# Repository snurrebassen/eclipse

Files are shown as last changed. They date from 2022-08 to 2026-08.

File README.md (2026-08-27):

# Eclipse

A 70% gasket-mount custom keyboard designed by [snurrebassen](https://geekhack.org/index.php?topic=113079), featuring a F-row-less TKL layout.

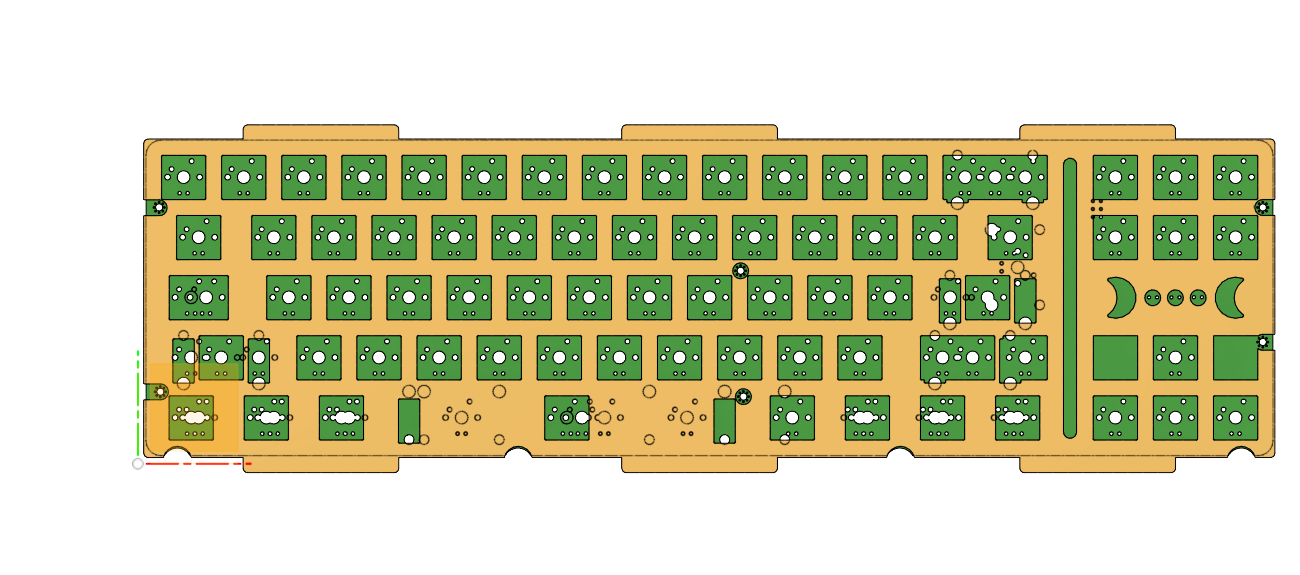
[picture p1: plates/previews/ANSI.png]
Eclipse


## Specifications

| Spec | Value |
|---|---|
| Layout | 70% (F-row-less TKL), 71 keys |
| Typing Angle | 7° |
| Front Height | 17.6mm |
| Dimensions | 374mm × 128.62mm |
| Mounting | Gasket mount (12× 50×5mm silicone gaskets) |
| Case Screws | 8× M3×11mm (bottom to top) |
| Daughterboard | 4× M2×4mm |
| Weight Screws | 2× M4×3.5mm (countersunk 90°) |

## Layout Compatibility

The Eclipse supports the following layouts:
- **ANSI**
- **ISO**
- Split-backspace
- Split right-shift
- Tsangan bottom row (WKL/Symmetrical)
- Split spacebar (2.75u / 1.25u / 2.25u)

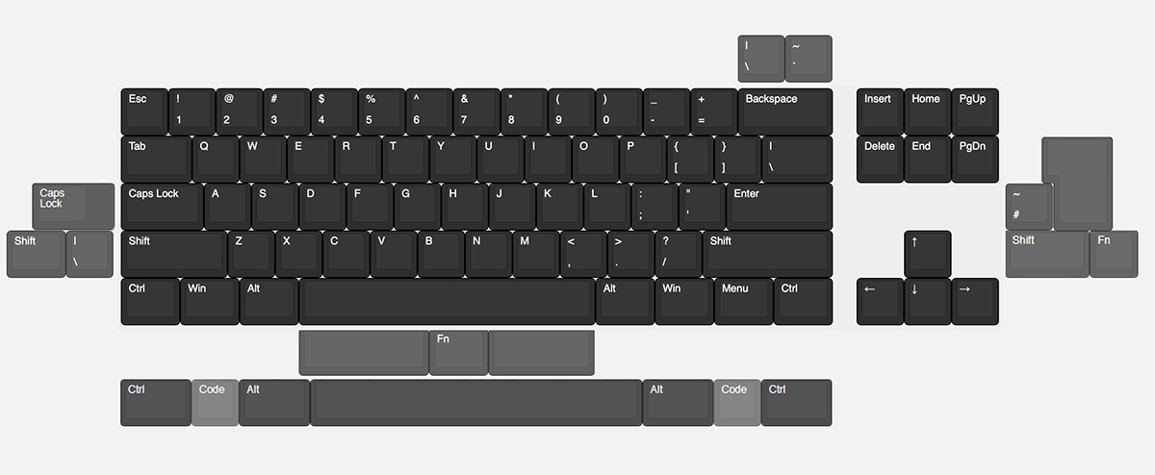
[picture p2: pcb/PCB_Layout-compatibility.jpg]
Layout Compatibility


## What's Included

```
eclipse/
├── pcb/                    # PCB resources
│   ├── eclipsepcb/        # Submodule: PCB design files (KiCad)
│   ├── Mechstudio (MKEU)/ # Pre-flashed VIAL hex
│   └── PCB_Layout-compatibility.jpg
├── plates/                 # Plate files (DXF)
│   ├── Eclipse_ANSI_12-2023.dxf
│   ├── Eclipse_ISO_12-2023.dxf
│   └── Eclipse_SPLIT-SPACE_12-2023.dxf
├── foam/                   # Foam cut files
├── Firmware/               # QMK firmware source
└── specs.md               # Full specifications
```

## PCB

The Eclipse PCB has evolved through several versions:

1. **Original PCB** — Designed by w3bb0, featured per-key RGB (SK6812mini) and underglow
2. **Mechstudio PCB** — Mykeyboard made production changes to fit newer specs, budget and available parts (MCU, SMDs). This is the version included as `pcb/Mechstudio (MKEU)/` with pre-flashed VIAL hex
3. **Martin PCB** — New cleaner PCB by [Martin](https://github.com/arnstadm/eclipsepcb) (not to be confused with w3bb0). Since the Mechstudio source files were no longer available, Martin designed a fresh PCB. **Does not feature underglow or per-key RGB**
4. **Khor PCB** — Hotswap PCB stocked by [Khor](https://khor.store/)

The PCB designs are available in the `pcb/eclipsepcb/` submodule.

### Firmware

Pre-compiled VIAL hex available in `pcb/Mechstudio (MKEU)/mechstudio_eclipse_vial.hex`

For building from source, see the [QMK firmware](https://github.com/snurrebassen/qmk_firmware/tree/master/keyboards/snurrebassen/eclipse) or use the submodule at `pcb/eclipsepcb/qmk files/`.

## Plates

Plates are 1.5mm thick and available in:
- ANSI
- ISO
- Split-space

Plate dimensions: **358.567mm × 110.317mm**

## Build Resources

### Required Parts
| Part | Quantity | Notes |
|---|---|---|
| M3×11mm screws | 8 | Socket cap, max Ø5.5mm |
| M2×4mm screws | 4 | Daughterboard |
| M4×3.5mm screws | 2 | Weight, countersunk 90° |
| Bumpons | 4 | 15×8mm, 1.5mm thick, Shore 50A silicone |
| Gaskets | 12 | 50×5mm, 1.5mm thick, Shore 50A silicone |

### Foam
Clearance between bottom case and PCB is 3mm. Foam thickness should not exceed 2mm.
- Foam dimensions: 358.167mm × 100.617mm

## History

- **IC**: February 20, 2020
- **Raffle/GB**: May 31, 2021
- **Production**: November 2021 (CNC milling)
- **Shipping**: July 2022

For the full timeline and discussion, see the [GeekHack thread](https://geekhack.org/index.php?topic=113079).

## Gallery

More renders available in `plates/previews/` and `plates/STEP/STEP previews/`.

## License

See [LICENSE.md](./LICENSE.md) — Eclipse is open source for personal use and modification.

## Acknowledgments

- **Designer**: snurrebassen
- **Original PCB**: w3bb0
- **Mechstudio PCB**: Mykeyboard.eu
- **Martin PCB**: Martin (arnstadm)
- **Khor PCB**: [Khor](https://khor.store/)
- **Community**: GeekHack, r/MechGroupBuys

---

*Eclipse (c) 2022 TypeLab / snurrebassen*

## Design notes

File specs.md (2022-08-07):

# Eclipse (2022)
* Designed by snurrebassen 
* PCB design by w3bb0
* Raffle date: 31.05.2021
* IC date: 20.02.2020

Specs:
* 7° typing angle
* 71 keys (Default ANSI)
* Front height: 17.6mm
* Length: 374mm
* Depth: 128.62mm
* 8 M3x11mm screws
* 4 M2x4mm screws (Daughterboard)
* 2 M4x3.5mm screws (Weight)

Layout compatibility:
* ANSI
* ISO
* Split-backspace
* Split-right shift
* Tsangan-bottom row

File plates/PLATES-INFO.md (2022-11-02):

Eclipse (c) 2022 TypeLab (snurrebassen)

Eclipse is a 70% F-row-less TKL custom keyboard. Here you can find resources for plates and eventually more.

The Eclipse PCB can hold the following popular layouts:
- ANSI
- ISO 
- Split backspace
- Split R-shift 
- Tsangan bottom row (WKL/Symmetrical bottom row)
- Split spacebar (2.75u, 1.25u, 2.25u)

Plate width: 358.567 mm <br />

Plate height/depth: 110.317 mm

The plates are available in each specific layout. 

If you require a unique combination and it is not uploaded in the plate files, contact snurrebassen for help.

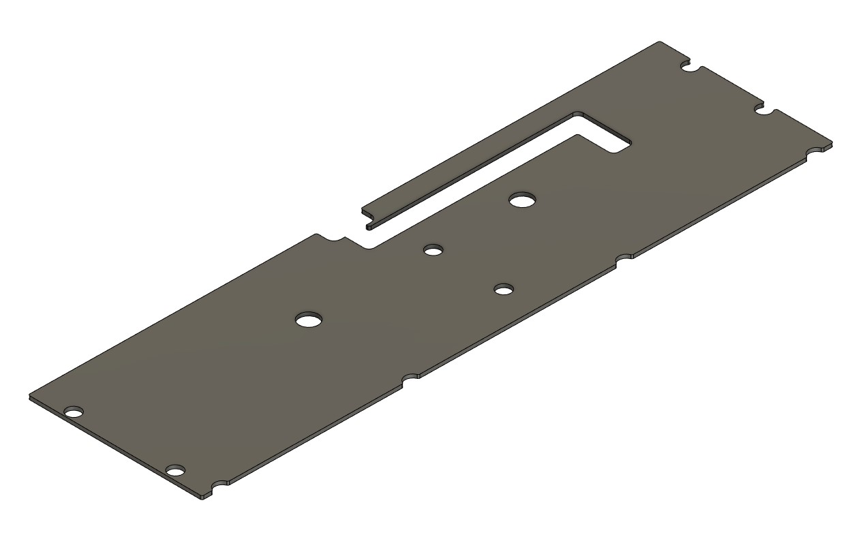
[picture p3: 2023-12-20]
foam/foam.jpg

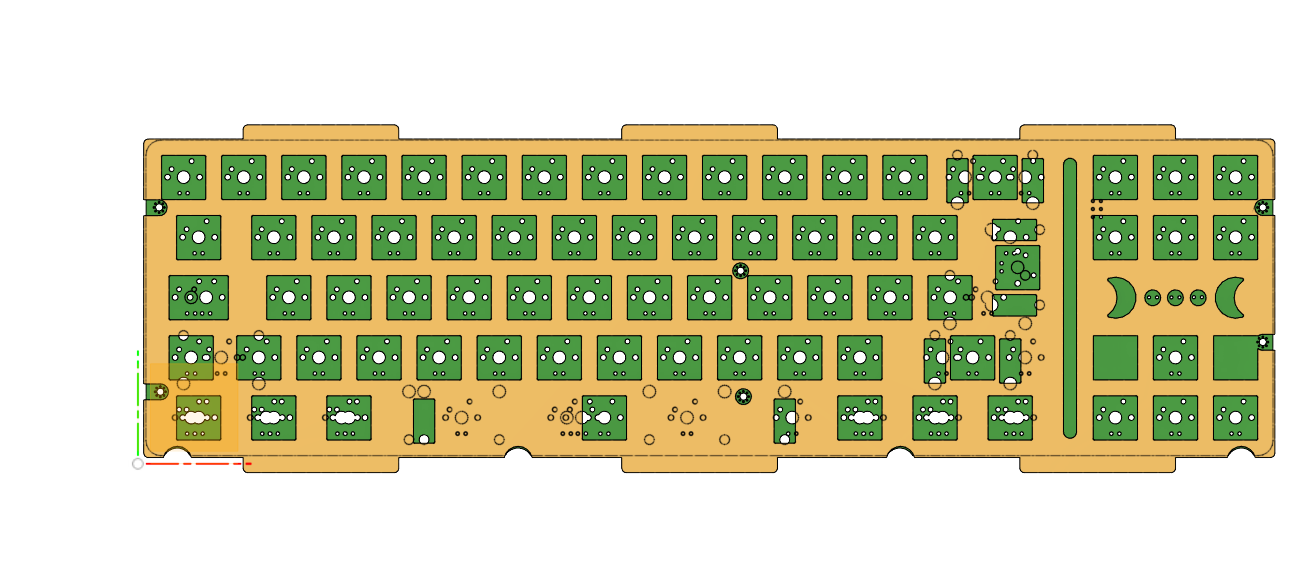
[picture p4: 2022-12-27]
plates/previews/ISO-WKL.png

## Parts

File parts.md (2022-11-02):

# Eclipse Parts info and measurements

<!-- 1. [Eclipse](#Eclipse-2022)-->
 
## Eclipse (2022) 
#### Screws
| Part | Quantity | Screw | Bit Size/Notes |
| --- | :---: | :---: | :---: |
| Bottom to top | 8 | M3x11mm  | Socket cap screw, max diameter 5.5mm
| Daughterboard | 4 | M2x4mm | Standard stabilizer/plate screws
| Weight | 2 | M4x3.5mm | Countersunk 90°

##### Optional Screws
For hotswap PCB, the PCB itself can be fastened with standard M2 (stabilizer screws) to the bottom case, it is recommended to use O-rings as a padding between the screw and the case.

#### Accessories
| Part | Description | Notes |
| ---- | --- | --- |
| Bumpons | 4x 15x8mm 1,5mm thick | Shore 50A Silicone, adhesive
| Gaskets | 12x 50x5mm 1,5mm thick | Shore 50A Silicone, adhesive
| Gaskets top sheet | Custom, 1,5mm thick | Shore 50A Silicone

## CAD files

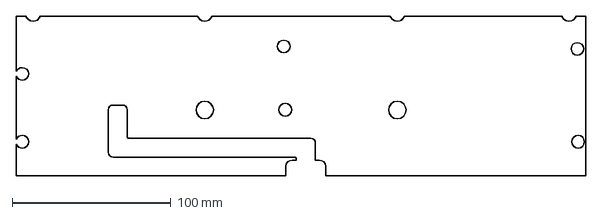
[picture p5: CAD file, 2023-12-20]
foam/Eclipse_Foam_2D-raw.dxf
358.2 x 100.6 mm

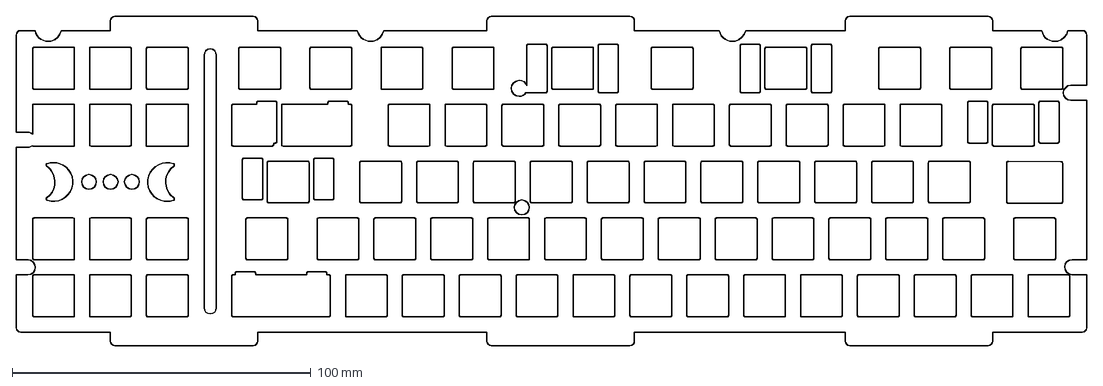
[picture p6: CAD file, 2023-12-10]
plates/Eclipse_SPLIT-SPACE_12-2023.dxf
358.6 x 110.3 mm

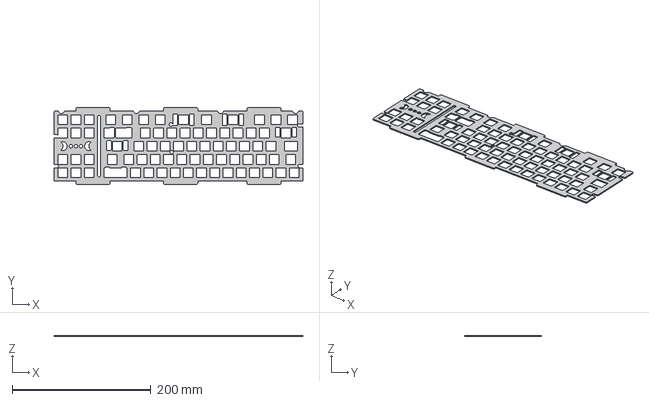
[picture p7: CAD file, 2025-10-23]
plates/STEP/Eclipse_SPLIT-SPACE_12-2023 v1.step
358.6 x 110.3 x 1.50 mm

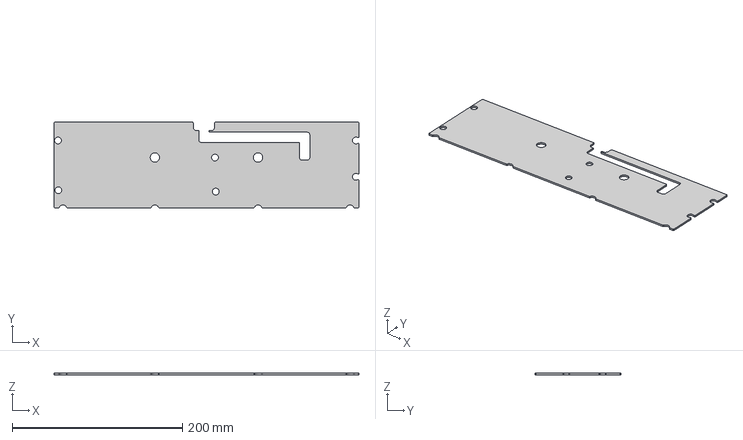
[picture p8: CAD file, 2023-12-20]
foam/Eclipse_Foam_3D.step
358.2 x 100.6 x 2.00 mm

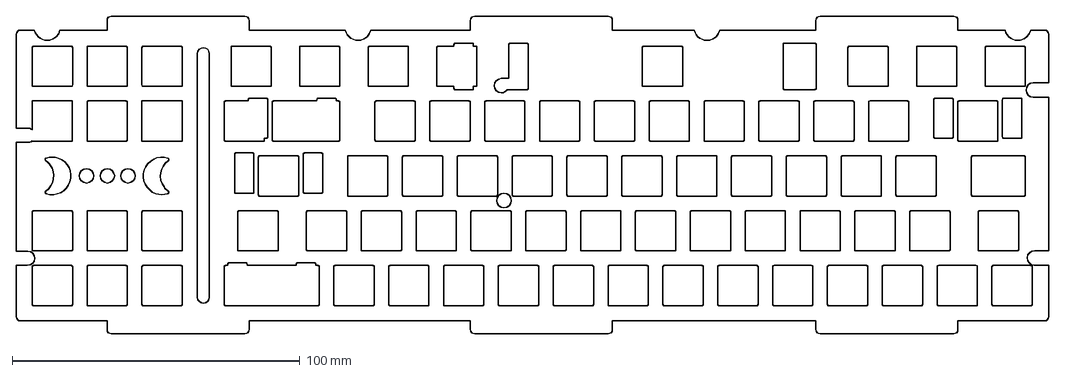
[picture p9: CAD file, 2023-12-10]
plates/Eclipse_ANSI_12-2023.dxf
358.6 x 110.3 mm

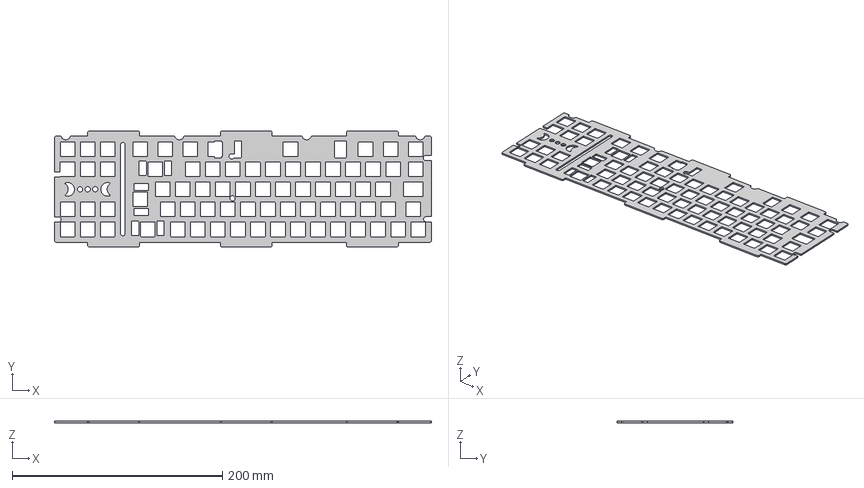
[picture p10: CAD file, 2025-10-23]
plates/STEP/Eclipse_ISO_12-2023 v1.step
358.6 x 110.3 x 1.50 mm

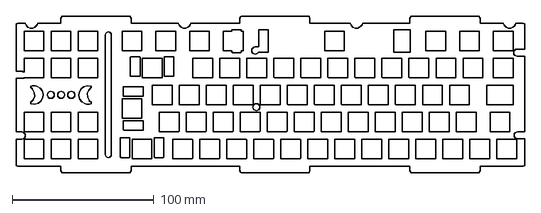
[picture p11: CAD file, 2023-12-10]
plates/Eclipse_ISO_12-2023.dxf
358.6 x 110.3 mm

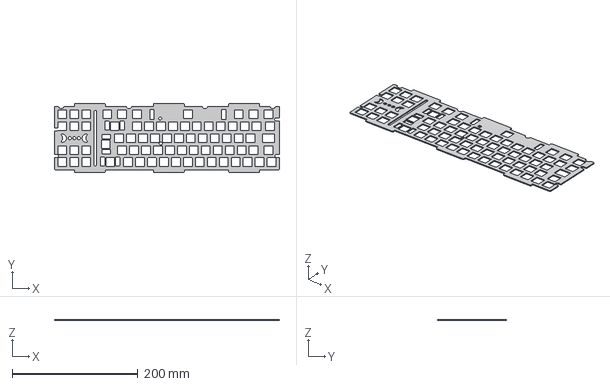
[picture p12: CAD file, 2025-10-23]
plates/STEP/Eclipse_ISO__WKL_12-2023 v0.step
358.6 x 110.3 x 1.50 mm

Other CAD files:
plates/STEP/Eclipse_WKL_12-2023 v1.step
plates/STEP/Eclipse_ANSI_12-2023 v1.step

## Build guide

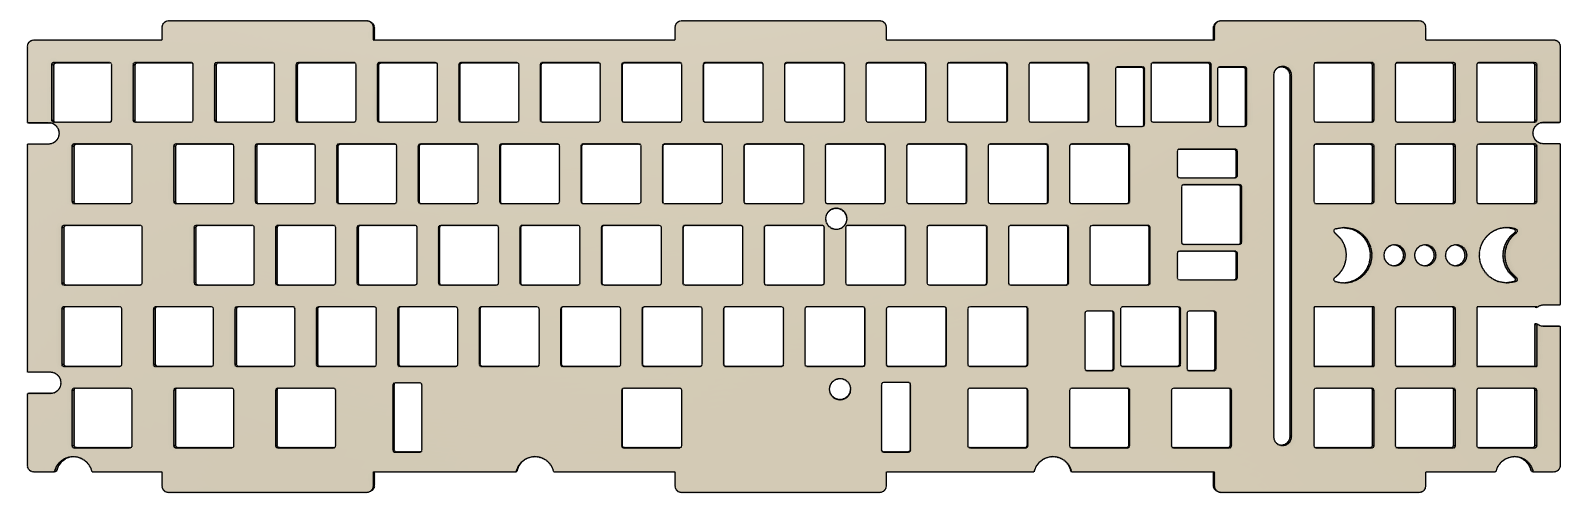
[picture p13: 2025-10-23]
plates/STEP/STEP previews/ISO_WKL_updated.png

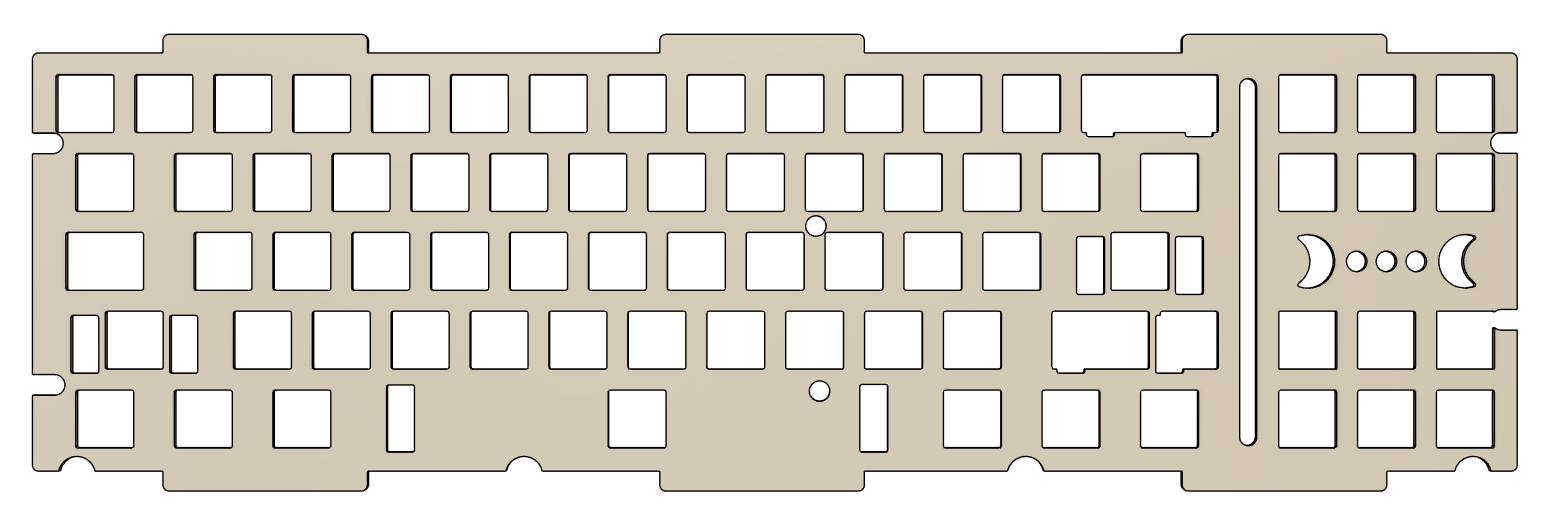
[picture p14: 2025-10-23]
plates/STEP/STEP previews/WKL_updated.png

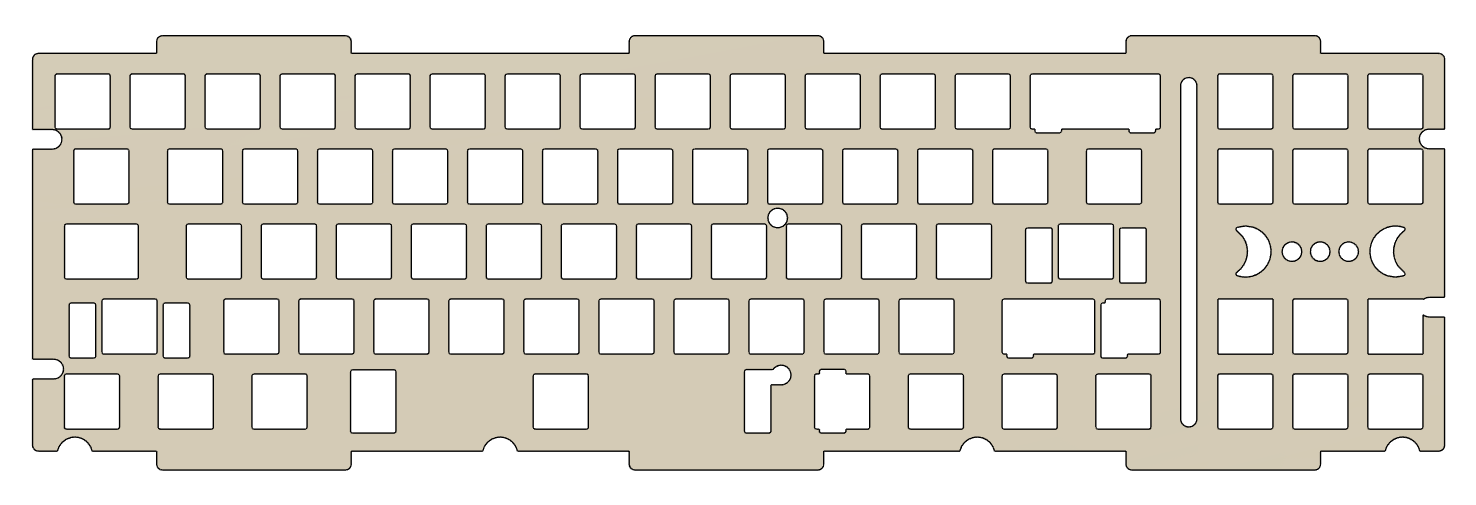
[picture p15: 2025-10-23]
plates/STEP/STEP previews/ANSI_updated.png

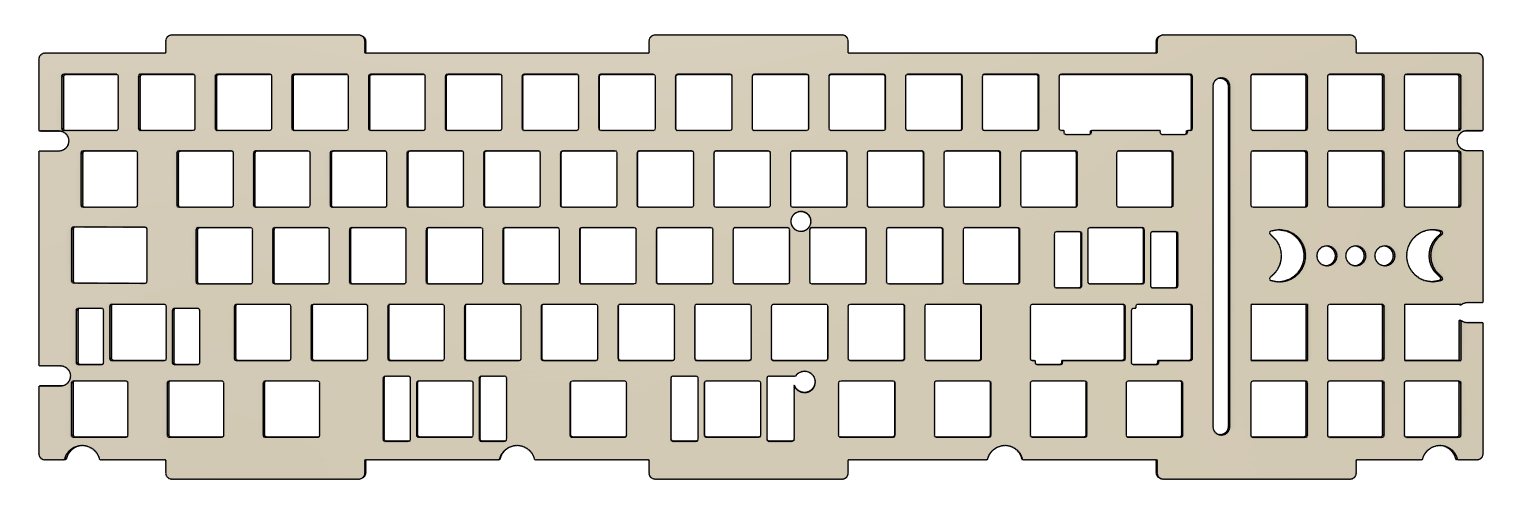
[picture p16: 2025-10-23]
plates/STEP/STEP previews/Split_Spacebar_updated.png

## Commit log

2022-11-02 Create plates
2022-11-02 Rename plates/previewss to plates/previews/previews goes here
2022-11-02 Image previews
    Image previews of plate files for human visual comprehension.
2022-11-17 Fixed DXF-files
    Exported DXF files properly as a single sketch.
    [Eclipse_ANSI-11-2022.dxf, Eclipse_ISO-WKL_11-2022.dxf, Eclipse_ISO_11-2022.dxf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]
2022-12-27 Fixed plate-files
    Fixed caps is not fixed, lol I fixed it.
    [Eclipse_ANSI_12-2022.dxf, Eclipse_ISO-WKL_12-2022.dxf, Eclipse_ISO_12-2022.dxf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]
2023-12-10 Delete plates/Eclipse_ANSI_12-2022.dxf
    Wrong stabilizer position
    [Eclipse_ANSI_12-2022.dxf]
2023-12-10 Delete plates/Eclipse_WKL_12-2022.dxf
    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
    [Eclipse_WKL_12-2022.dxf]
2023-12-10 Delete plates/Eclipse_ISO-WKL_12-2022.dxf
    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
    [Eclipse_ISO-WKL_12-2022.dxf]
2023-12-10 Delete plates/Eclipse_ISO_12-2022.dxf
    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
    [Eclipse_ISO_12-2022.dxf]
2023-12-10 Fixed stabilizer position - standard + wkl
    [Eclipse_ANSI_12-2023.dxf, Eclipse_ISO_12-2023.dxf]
2023-12-10 Delete plates/Eclipse_SPLIT-SPACE_12-2022.dxf
    Fixed stabilizer position
    [Eclipse_SPLIT-SPACE_12-2022.dxf]
2023-12-10 Fixed stabilizer positions
    [Eclipse_SPLIT-SPACE_12-2023.dxf]
2025-10-23 added 3D STEP files of plates + previews
    Plate thickness 1.5mm
    [Eclipse_ANSI_12-2023 v1.step, Eclipse_ISO_12-2023 v1.step, Eclipse_ISO__WKL_12-2023 v0.step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]
2026-01-15 Original myekeyboard PCB vial hex
2026-08-27 Move PCB files to pcb/ folder
2026-08-27 Update PCB history and acknowledgments
